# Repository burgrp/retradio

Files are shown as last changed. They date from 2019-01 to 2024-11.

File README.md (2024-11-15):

# Orange Pi Zero based web radio

## I2C peripherals

### Rotary EncoderX

#### Addressing

* 0x40 NN Volume
* 0x41 AN Balance
* 0x42 BN Treble
* 0x43 NC Bass
* 0x44 AC Aperture
* 0x45 BC Tuning
* 0x46 ND Band

### Push buttons

* 0x49 NN 7 Bands switch

## Docker image

Start buildx builder

```text
docker buildx create --name cross
docker buildx inspect --bootstrap
```

Build the image

```sh
docker run --rm --privileged docker/binfmt:820fdd95a9972a5308930a2bdfb8573dd4447ad3
docker buildx build --platform linux/arm/v7 . -t burgrp/retradio --push
```

## DEVICE.FARM

### OS installation
```sh
defa install device-id /dev/your-sd-card --wifi=ssid:password --ssh - --dto $PWD/mb-a/dto --root $PWD/mb-a/root
```

### Retradio service installation
```sh
defa proxy device-id -- docker pull burgrp/retradio
defa proxy device-id -- docker-compose up -d
```
or

```sh
./update-devices device-id ...
```

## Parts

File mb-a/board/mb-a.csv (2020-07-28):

Quantity | Designator | Designation
1 | C1 | 470n | o
2 | C14,C15 | 1n | o
4 | C2,C3,C12,C13 | 1u | o
2 | C4,C19 | 100u/12V | o
2 | C5,C10 | 470u/16V | o
3 | C6,C9,C17 | 10u | o
5 | C7,C8,C16,C11,C18 | 100n | o
1 | J1 | Power
1 | J2 | Speaker
2 | L1,L2 | 600R | o
1 | L3 | 6.8uH | o
1 | M1 | Orange-Pi-Zero
1 | R1 | 10R | o
3 | R2,R3,R4 | 1k5 | o
1 | R5 | 100k | !!!
1 | R6 | 30.9k 1% | o
1 | R7 | 4.22k 1% | o
1 | U1 | FR8205 | !!!
1 | U2 | PAM8320 | !!!
1 | X1 | I2C-6P

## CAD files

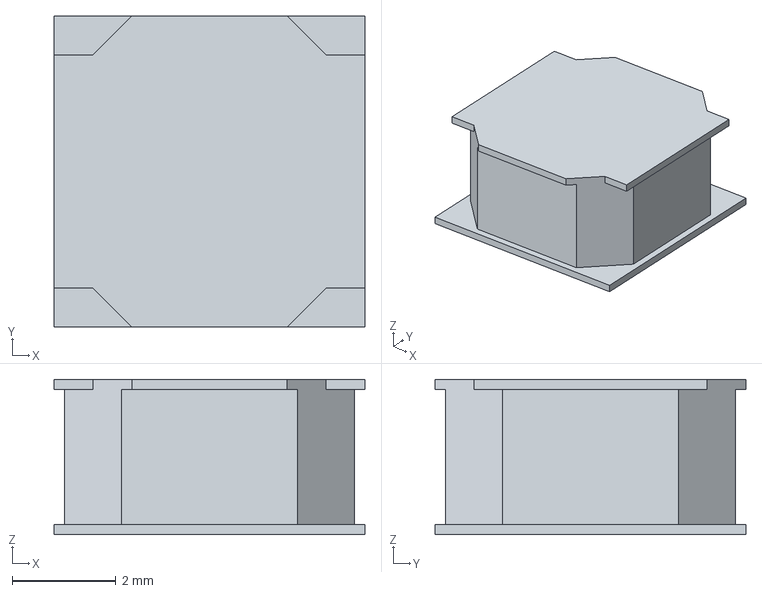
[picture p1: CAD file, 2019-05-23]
mb-a/board/CENKER-CKCS - CKCS6028.step
6.00 x 6.00 x 3.00 mm

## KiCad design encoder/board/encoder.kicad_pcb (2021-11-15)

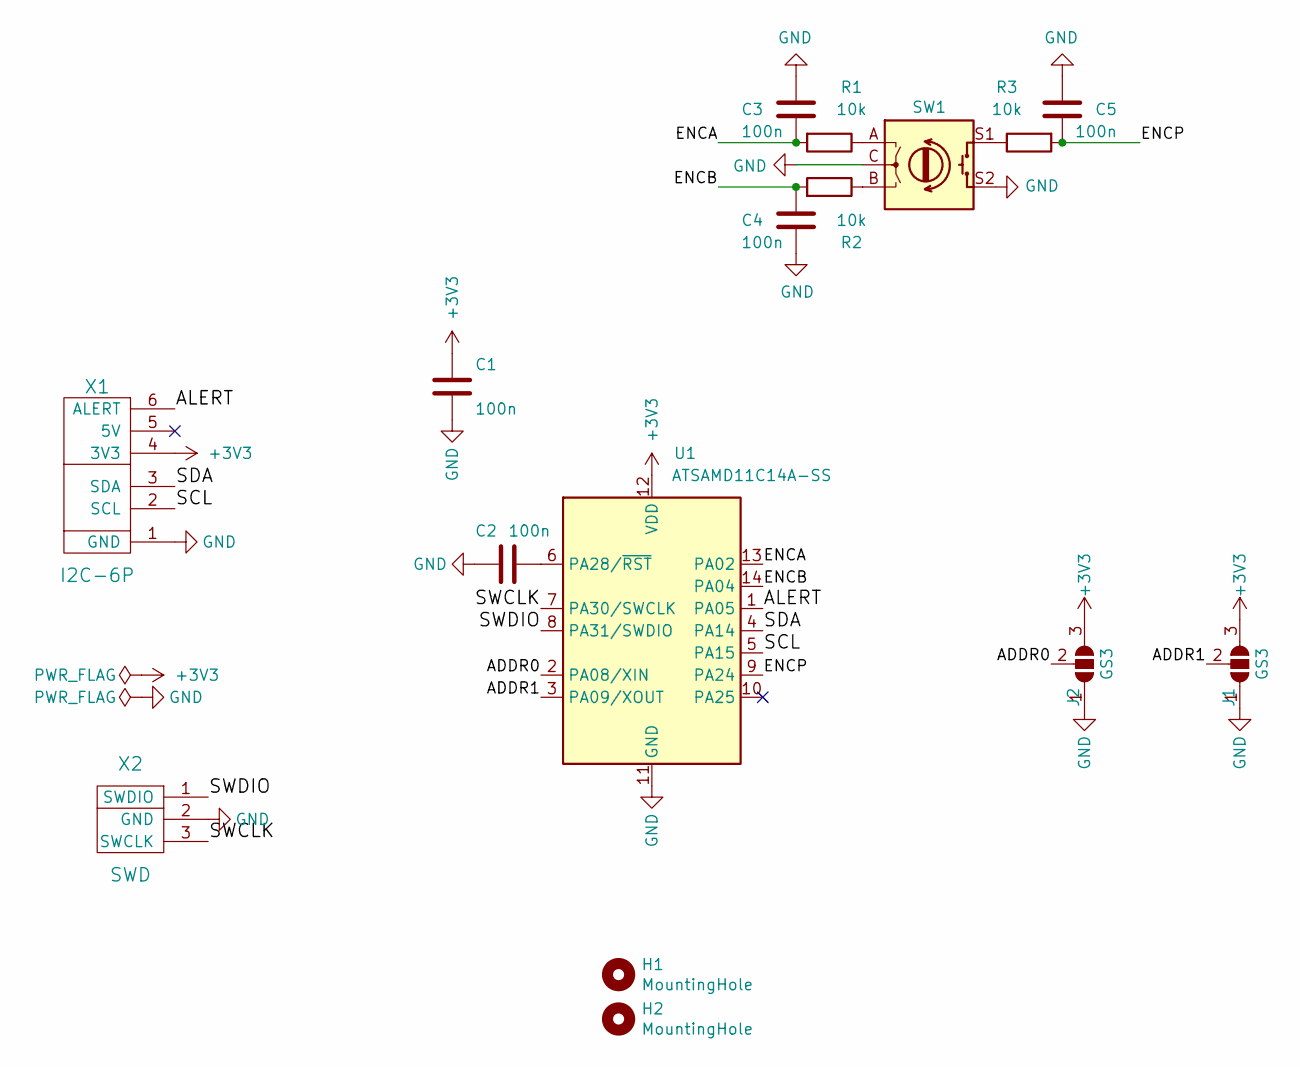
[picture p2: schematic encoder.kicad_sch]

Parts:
C1, C2, C3, C4, C5: 100n; C_0805_2012Metric_Pad1.18x1.45mm_HandSolder
H1, H2: MountingHole; MountingHole_2.5mm
J1, J2: GS3; SolderJumper-3_P1.3mm_Open_Pad1.0x1.5mm
R1, R2, R3: 10k; R_0805_2012Metric_Pad1.20x1.40mm_HandSolder
SW1: RotaryEncoder_Switch; RotaryEncoder_Bourns_PEC12R-4x20F-Sxxxx
U1: ATSAMD11C14A-SS; SOIC-14_3.9x8.7mm_P1.27mm
X1: I2C-6P; IDC-Header_2x03_P2.54mm_Vertical
X2: SWD

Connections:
+3V3: C1.1, J1.3 (B), J2.3 (B), U1.12 (VDD), X1.4 (3V3)
/ADDR0: J2.2 (C), U1.2 (PA08/XIN)
/ADDR1: J1.2 (C), U1.3 (PA09/XOUT)
/ALERT: U1.1 (PA05), X1.6 (ALERT)
/ENCA: C3.2, R1.2, U1.13 (PA02)
/ENCB: C4.1, R2.2, U1.14 (PA04)
/ENCP: C5.2, R3.2, U1.9 (PA24)
/SCL: U1.5 (PA15), X1.2 (SCL)
/SDA: U1.4 (PA14), X1.3 (SDA)
/SWCLK: U1.7 (PA30/SWCLK), X2.3 (SWCLK)
/SWDIO: U1.8 (PA31/SWDIO), X2.1 (SWDIO)
GND: C1.2, C2.2, C3.1, C4.2, C5.1, J1.1 (A), J2.1 (A), SW1.C, SW1.S2, U1.11 (GND), X1.1 (GND), X2.2 (GND)
unnamed: C2.1, U1.6 (PA28/~RST)
unnamed: R1.1, SW1.A
unnamed: R2.1, SW1.B
unnamed: R3.1, SW1.S1

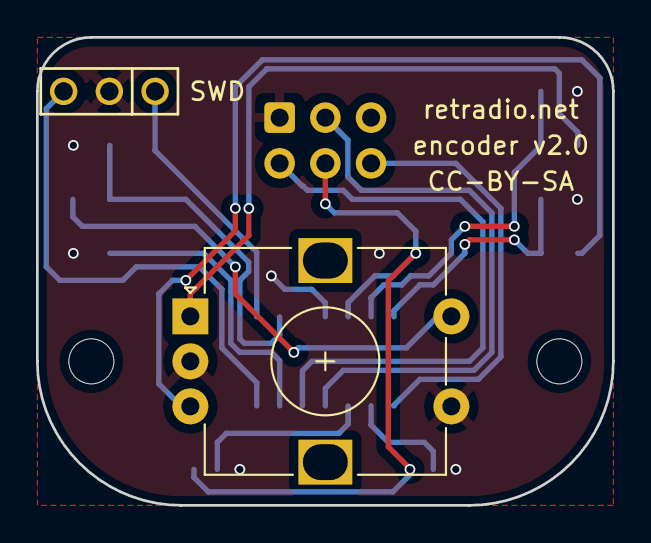
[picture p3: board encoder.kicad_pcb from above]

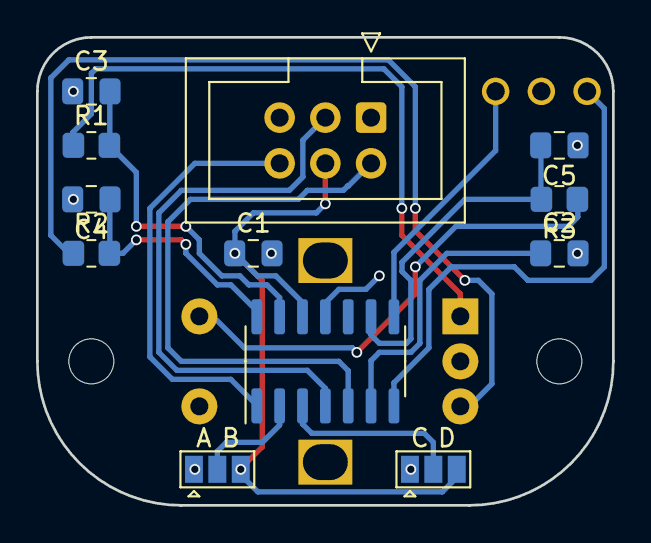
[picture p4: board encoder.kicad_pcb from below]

Board: 2 copper layers, 32.0 x 26.0 mm, 16 parts (14 on the bottom side), 16 nets.

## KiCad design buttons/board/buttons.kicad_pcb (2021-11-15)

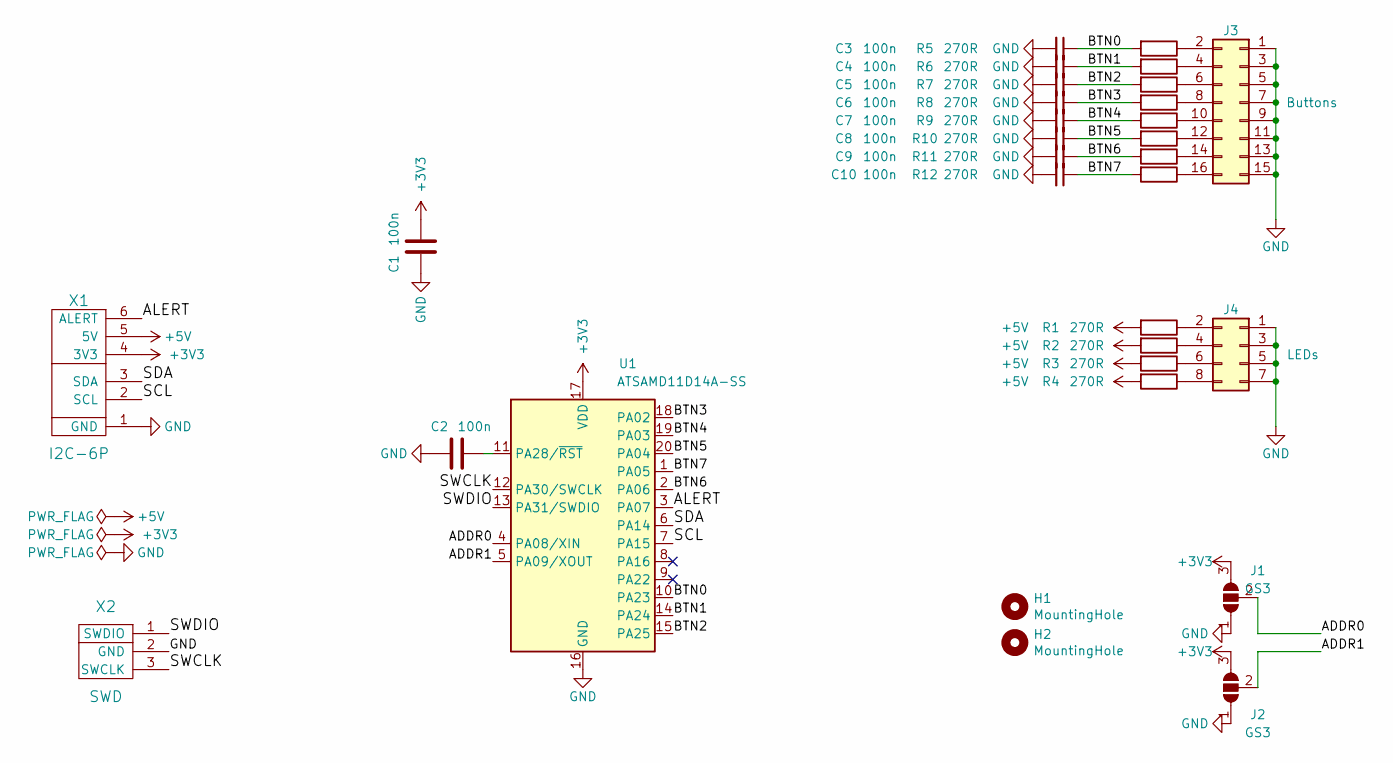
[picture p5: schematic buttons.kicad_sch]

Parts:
C1, C2, C3, C4, C5, C6, C7, C8, C9, C10: 100n; C_0805_2012Metric_Pad1.18x1.45mm_HandSolder
H1, H2: MountingHole; MountingHole_2.5mm
J1, J2: GS3; SolderJumper-3_P1.3mm_Open_Pad1.0x1.5mm
J3: Buttons; PinHeader_2x08_P2.54mm_Vertical
J4: LEDs; PinHeader_2x04_P2.54mm_Vertical
R1, R2, R3, R4, R5, R6, R7, R8, R9, R10, R11, R12: 270R; R_0805_2012Metric_Pad1.20x1.40mm_HandSolder
U1: ATSAMD11D14A-SS; SOIC-20W_7.5x12.8mm_P1.27mm
X1: I2C-6P; IDC-Header_2x03_P2.54mm_Vertical
X2: SWD

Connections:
+3V3: C1.1, J1.3 (B), J2.3 (B), U1.17 (VDD), X1.4 (3V3)
+5V: R1.2, R2.2, R3.2, R4.2, X1.5 (5V)
/ADDR0: J1.2 (C), U1.4 (PA08/XIN)
/ADDR1: J2.2 (C), U1.5 (PA09/XOUT)
/ALERT: U1.3 (PA07), X1.6 (ALERT)
/BTN0: C3.1, R5.2, U1.10 (PA23)
/BTN1: C4.1, R6.2, U1.14 (PA24)
/BTN2: C5.1, R7.2, U1.15 (PA25)
/BTN3: C6.1, R8.2, U1.18 (PA02)
/BTN4: C7.1, R9.2, U1.19 (PA03)
/BTN5: C8.1, R10.2, U1.20 (PA04)
/BTN6: C9.1, R11.2, U1.2 (PA06)
/BTN7: C10.1, R12.2, U1.1 (PA05)
/SCL: U1.7 (PA15), X1.2 (SCL)
/SDA: U1.6 (PA14), X1.3 (SDA)
/SWCLK: U1.12 (PA30/SWCLK), X2.3 (SWCLK)
/SWDIO: U1.13 (PA31/SWDIO), X2.1 (SWDIO)
GND: C1.2, C2.2, C3.2, C4.2, C5.2, C6.2, C7.2, C8.2, C9.2, C10.2, J1.1 (A), J2.1 (A), J3.1, J3.3, J3.5, J3.7, J3.9, J3.11, J3.13, J3.15, J4.1, J4.3, J4.5, J4.7, U1.16 (GND), X1.1 (GND), X2.2 (GND)
unnamed: C2.1, U1.11 (PA28/~RST)
unnamed: J3.2, R5.1
unnamed: J3.4, R6.1
unnamed: J3.6, R7.1
unnamed: J3.8, R8.1
unnamed: J3.10, R9.1
unnamed: J3.12, R10.1
unnamed: J3.14, R11.1
unnamed: J3.16, R12.1
unnamed: J4.2, R1.1
unnamed: J4.4, R2.1
unnamed: J4.6, R3.1
unnamed: J4.8, R4.1

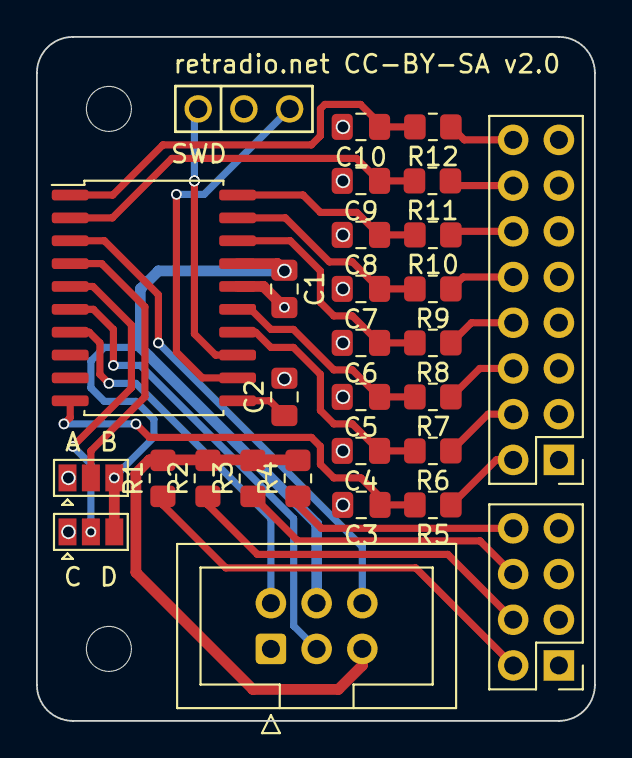
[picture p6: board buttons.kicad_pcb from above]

Board: 2 copper layers, 31.0 x 38.0 mm, 31 parts (0 on the bottom side), 31 nets.

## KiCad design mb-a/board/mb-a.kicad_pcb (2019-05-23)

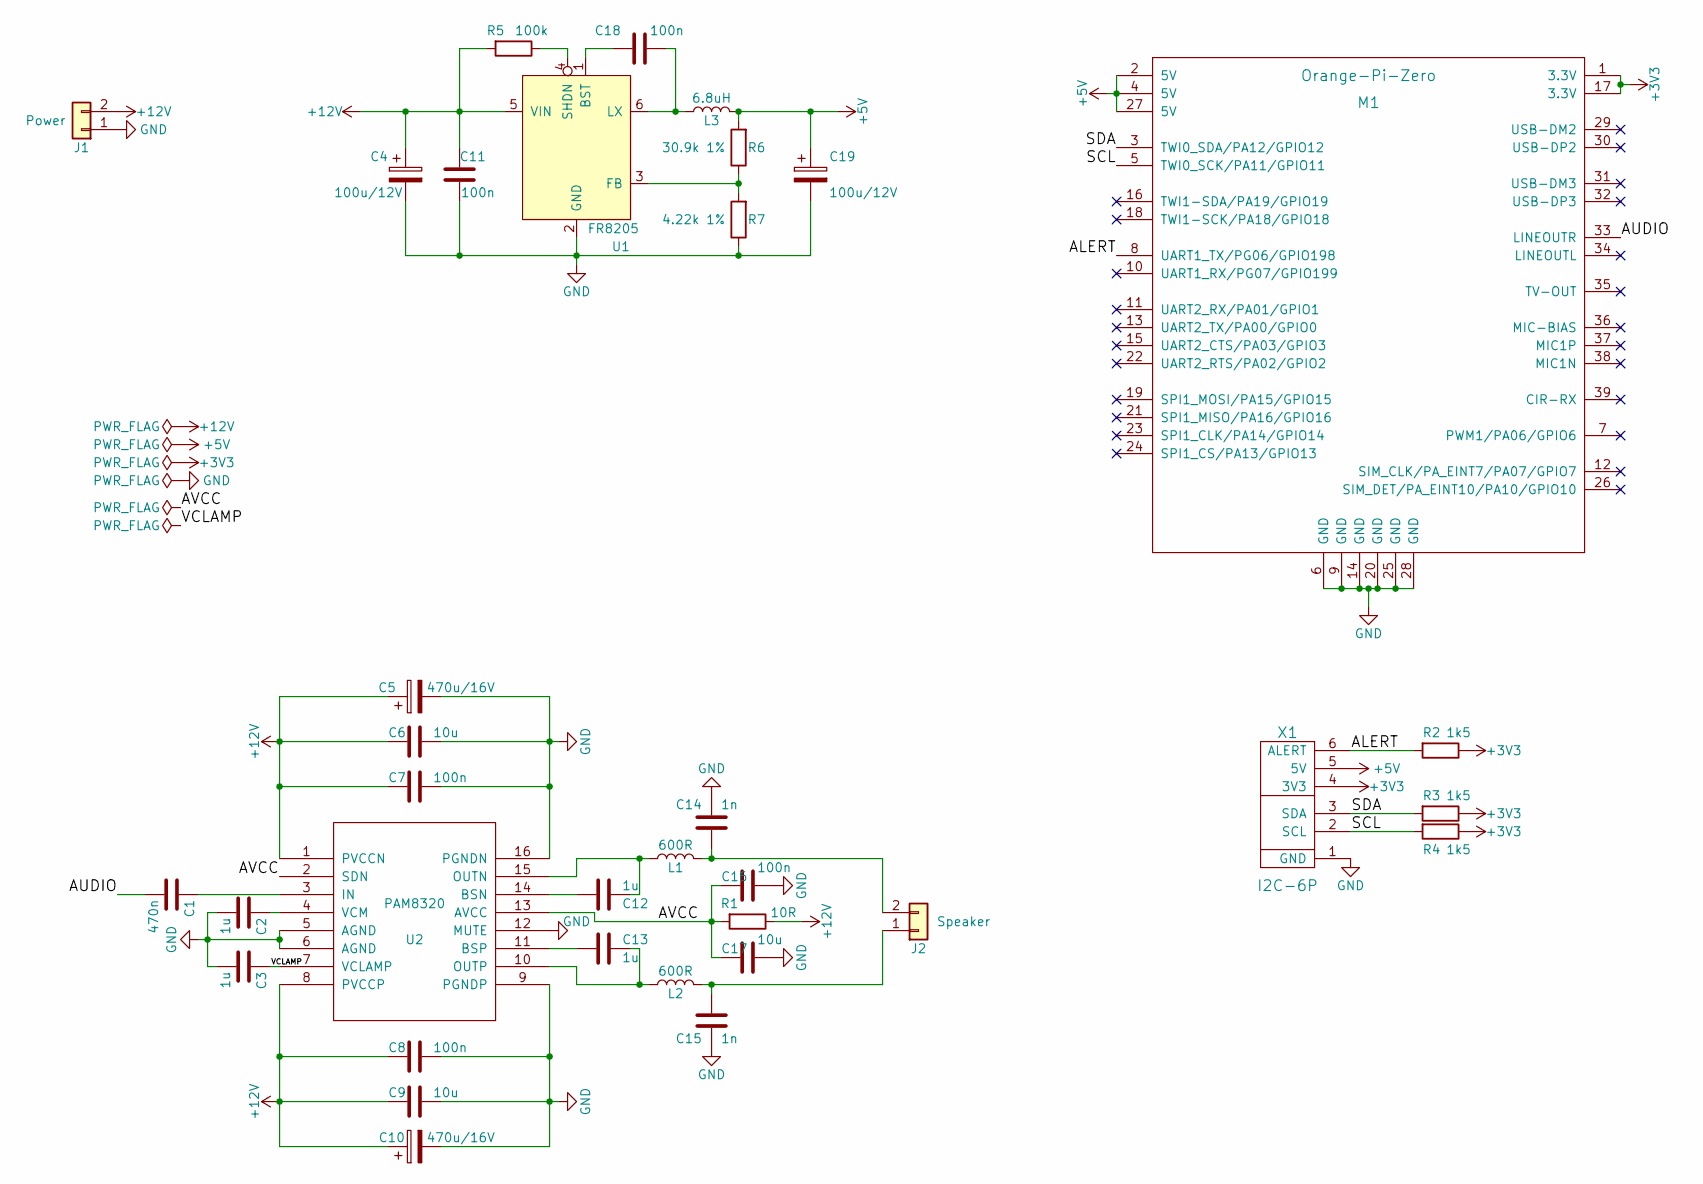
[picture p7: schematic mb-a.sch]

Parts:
C1: 470n; C_0805_2012Metric
C2, C3, C12, C13: 1u; C_0805_2012Metric
C4, C19: 100u/12V; CP_Elec_6.3x5.4
C5, C10: 470u/16V; CP_Elec_8x10
C6, C9, C17: 10u; C_0805_2012Metric
C7, C8, C11, C16, C18: 100n; C_0805_2012Metric
C14, C15: 1n; C_0805_2012Metric
J1: Power; DG301-5.0-02
J2: Speaker; DG301-5.0-02
L1, L2: 600R; L_0805_2012Metric
L3: 6.8uH; L_Taiyo-Yuden_NR-60xx_HandSoldering
M1: Orange-Pi-Zero
R1: 10R; R_0805_2012Metric
R2, R3, R4: 1k5; R_0805_2012Metric
R5: 100k; R_0805_2012Metric
R6: 30.9k 1%; R_0805_2012Metric
R7: 4.22k 1%; R_0805_2012Metric
U1: FR8205; SOT-23-6
U2: PAM8320; SOIC-16_3.9x9.9mm_P1.27mm
X1: I2C-6P; IDC-Header_2x03_P2.54mm_Vertical

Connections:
+3V3: M1.1 (3.3V), M1.17 (3.3V), R2.1, R3.1, R4.1, X1.4 (3V3)
+5V: C19.1, L3.2, M1.2 (5V), M1.4 (5V), M1.27 (5V), R6.2, X1.5 (5V)
+12V: C4.1, C5.1, C6.2, C7.2, C8.2, C9.2, C10.1, C11.2, J1.2, R1.1, R5.2, U1.5 (VIN), U2.1 (PVCCN), U2.8 (PVCCP)
/ALERT: M1.8 (UART1_TX/PG06/GPIO198), R2.2, X1.6 (ALERT)
/AUDIO: C1.2, M1.33 (LINEOUTR)
/AVCC: C16.2, C17.2, R1.2, U2.2 (SDN), U2.13 (AVCC)
/SCL: M1.5 (TWI0_SCK/PA11/GPIO11), R4.2, X1.2 (SCL)
/SDA: M1.3 (TWI0_SDA/PA12/GPIO12), R3.2, X1.3 (SDA)
/VCLAMP: C3.1, U2.7 (VCLAMP)
GND: C2.2, C3.2, C4.2, C5.2, C6.1, C7.1, C8.1, C9.1, C10.2, C11.1, C14.2, C15.1, C16.1, C17.1, C19.2, J1.1, M1.6 (GND), M1.9 (GND), M1.14 (GND), M1.20 (GND), M1.25 (GND), M1.28 (GND), R7.1, U1.2 (GND), U2.5 (AGND), U2.6 (AGND), U2.9 (PGNDP), U2.12 (MUTE), U2.16 (PGNDN), X1.1 (GND)
unnamed: C1.1, U2.3 (IN)
unnamed: C2.1, U2.4 (VCM)
unnamed: C12.1, L1.1, U2.15 (OUTN)
unnamed: C12.2, U2.14 (BSN)
unnamed: C13.1, L2.1, U2.10 (OUTP)
unnamed: C13.2, U2.11 (BSP)
unnamed: C14.1, J2.2, L1.2
unnamed: C15.2, J2.1, L2.2
unnamed: C18.1, U1.1 (BST)
unnamed: C18.2, L3.1, U1.6 (LX)
unnamed: R5.1, U1.4 (SHDN)
unnamed: R6.1, R7.2, U1.3 (FB)

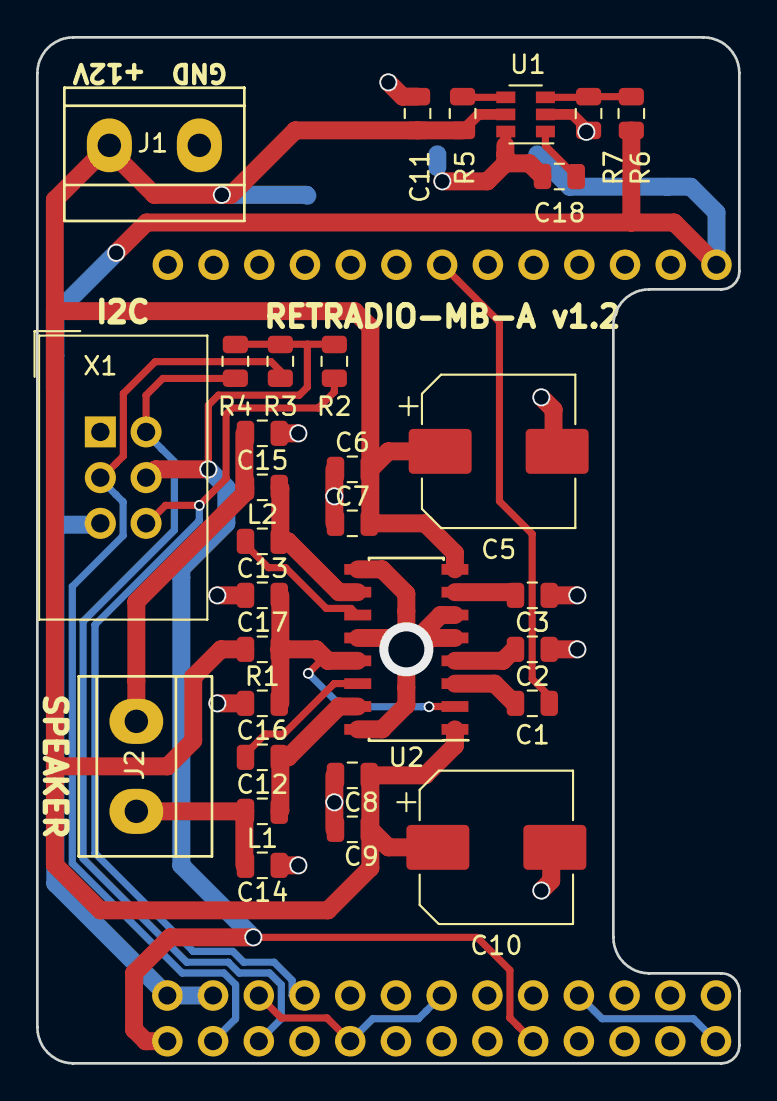
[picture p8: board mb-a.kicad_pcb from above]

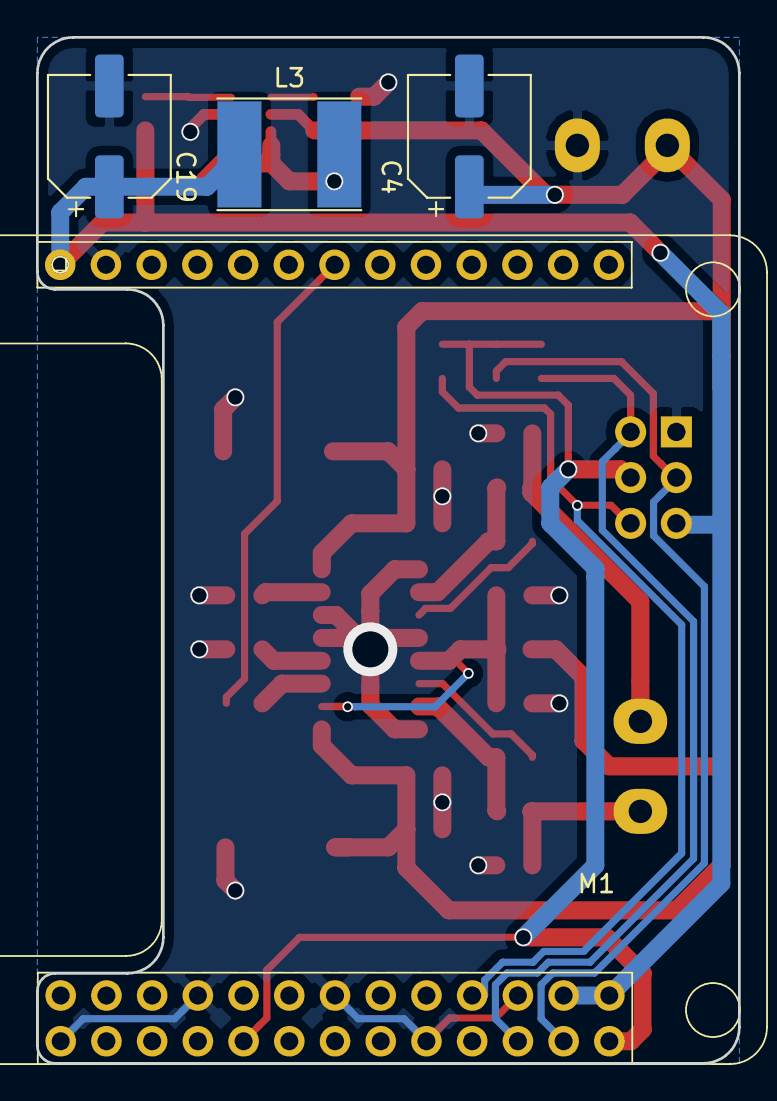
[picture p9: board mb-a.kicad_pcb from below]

Board: 2 copper layers, 39.0 x 57.0 mm, 35 parts (4 on the bottom side), 22 nets.

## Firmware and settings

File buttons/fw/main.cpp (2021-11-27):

const int PIN_ADDR1 = 8;
const int PIN_ADDR2 = 9;

const int PIN_SAFEBOOT = 16;

const int PIN_BUTTONS[8] = {23, 24, 25, 2, 3, 4, 6, 5};

const int PIN_SDA = 14;
const int PIN_SCL = 15;

const int KEY_TIMER_MS = 100;

class Device {
public:
  class : public atsamd::i2c::Slave {
  public:
    Device *that;

    struct {
      unsigned char protocol = 2;
      unsigned char buttons = 0;
    } __attribute__((packed)) txData;

    void init(Device *that, int address) {
      this->that = that;

      Slave::init(address, 0, atsamd::i2c::AddressMode::MASK, 0, target::gclk::CLKCTRL::GEN::GCLK0, PIN_SDA, PIN_SCL,
                  target::port::PMUX::PMUXE::C);
    }

    virtual int getTxByte(int index) { return index < sizeof(txData) ? ((unsigned char *)&txData)[index] : 0; }

  } slave;

  class : public genericTimer::Timer {
  public:
    Device *that;

    void init(Device *that) {
      this->that = that;
      start(KEY_TIMER_MS / 10);
    }

    void onTimer() {

      int states = 0;
      for (int button = 0; button < 8; button++) {
        int pin = PIN_BUTTONS[button];
        states |= (!(target::PORT.IN >> pin & 1) & 1) << button;
      }

      that->slave.txData.buttons = states;
      
      start(KEY_TIMER_MS / 10);
    }

  } timer;

  void init() {

    // TC1 for motor PWM

    target::PM.APBCMASK.setTC(1, true);

    target::GCLK.CLKCTRL = target::GCLK.CLKCTRL.bare()
                               .setID(target::gclk::CLKCTRL::ID::TC1_TC2)
                               .setGEN(target::gclk::CLKCTRL::GEN::GCLK0)
                               .setCLKEN(true);

    while (target::GCLK.STATUS.getSYNCBUSY())
      ;

    timer.init(this);

    int address = 0x49 + atsamd::configPin::readConfigPin(PIN_ADDR1) + 3 * atsamd::configPin::readConfigPin(PIN_ADDR2);
    slave.init(this, address);
  }
};

Device device;

void interruptHandlerSERCOM0() { device.slave.interruptHandlerSERCOM(); }

void initApplication() {

  // enable safeboot
  atsamd::safeboot::init(PIN_SAFEBOOT, false);

  // MCU clocked at 8MHz
  target::SYSCTRL.OSC8M.setPRESC(target::sysctrl::OSC8M::PRESC::_1);
  genericTimer::clkHz = 8E6;

  device.init();

  // enable interrupts
  target::NVIC.IPR[target::interrupts::External::SERCOM0 >> 2].setPRI(target::interrupts::External::SERCOM0 & 0x03, 3);
  target::NVIC.ISER.setSETENA(1 << target::interrupts::External::SERCOM0);

  // configure buttons
  for (int button = 0; button < 8; button++) {
    int pin = PIN_BUTTONS[button];
    target::PORT.DIRCLR = 1 << pin;
    target::PORT.PINCFG[pin].setINEN(true).setPULLEN(true);
    target::PORT.OUTSET = 1 << pin;
  }
}

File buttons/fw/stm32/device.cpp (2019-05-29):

const int buttonCount = 7;

class Device : public i2c::hw::BufferedSlave, Alert
{

	iwdg::Driver iwdg;

	const int pinButton0 = 0;

	const int pinAddrAB = 3;
	const int pinAddrCD = 4;

	const int pinAlert = 7;
	const int pinScl = 9;
	const int pinSda = 10;

	struct
	{
		unsigned char protocol = 1;
		unsigned char down = 0;
		unsigned char up = 0;
	} __attribute__((packed)) txData;

  public:
	Button buttons[buttonCount];

	void init()
	{
		target::RCC.AHBENR.setIOPAEN(true);

		iwdg.init();

		// I2C peripheral
		target::GPIOA.BSRR.setBS(pinAlert, 1);
		target::GPIOA.OTYPER.setOT(pinAlert, 1);
		target::GPIOA.MODER.setMODER(pinAlert, 1);
		target::GPIOA.AFRH.setAFRH(pinScl, 4);
		target::GPIOA.AFRH.setAFRH(pinSda, 4);
		target::GPIOA.MODER.setMODER(pinScl, 2);
		target::GPIOA.MODER.setMODER(pinSda, 2);
		target::RCC.APB1ENR.setC_EN(1, 1);
		target::NVIC.ISER.setSETENA(1 << target::interrupts::External::I2C1);

		int address = 0x49 + probeTriStateInput(&target::GPIOA, pinAddrAB) + 3 * probeTriStateInput(&target::GPIOA, pinAddrCD);
		i2c::hw::BufferedSlave::init(&target::I2C1, address, NULL, 0, (unsigned char *)&txData, sizeof(txData));

		for (int b = 0; b < buttonCount; b++) {
			buttons[b].init(&target::GPIOA, pinButton0 + b, this);
		}
	}

	void alert()
	{
		target::GPIOA.BSRR.setBR(pinAlert, 1);
	}

	virtual void onTxStart()
	{
		txData.down = 0;
		txData.up = 0;
		for (int b = 0; b < buttonCount; b++) {
			int flags = buttons[b].readFlags();
			txData.down |= (flags & 1) << b;
			txData.up |= ((flags >> 1) & 1) << b;
		}
		target::GPIOA.BSRR.setBS(pinAlert, 1);
	}

	void handleButtonInterrupt() {
		for (int b = 0; b < buttonCount; b++) {
			buttons[b].handleInterrupt();
		}
	}
};

Device device;

void interruptHandlerI2C1()
{
	device.handleInterrupt();
}

void interruptHandlerEXTI0_1()
{
	device.handleButtonInterrupt();
}

void interruptHandlerEXTI2_3()
{
	device.handleButtonInterrupt();
}

void interruptHandlerEXTI4_15()
{
	device.handleButtonInterrupt();
}

void initApplication()
{
	device.init();

	// EXTI
	target::NVIC.ISER.setSETENA(1 << target::interrupts::External::EXTI0_1);
	target::NVIC.ISER.setSETENA(1 << target::interrupts::External::EXTI2_3);
	target::NVIC.ISER.setSETENA(1 << target::interrupts::External::EXTI4_15);
}

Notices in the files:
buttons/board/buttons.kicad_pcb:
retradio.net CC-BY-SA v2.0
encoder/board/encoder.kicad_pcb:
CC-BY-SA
